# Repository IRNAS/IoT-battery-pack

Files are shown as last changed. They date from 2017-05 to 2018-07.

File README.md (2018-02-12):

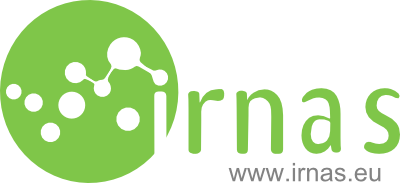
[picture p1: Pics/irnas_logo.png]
irnas_logo


# PiRA - Power in Responsive Applications (IoT battery pack - modular)

This repository contains the design of [PiRA](http://irnas.eu/pira), a modular IoT battery pack based on the integrated version developed for [Safecst Solarcast](https://github.com/IRNAS/Solarcast) sensor device. It is an open source universal solution for solar powered IoT devices implementing all commonly required features:

1. charging,
2. battery monitoring,
3. voltage regulation,
4. power scheduling,
5. battery protection,
6. standard LiPo cell usage,
7. optional on board processor.

This battery pack solution was designed to reduce the development time and costs of bringing IoT devices from idea to functional prototypes.

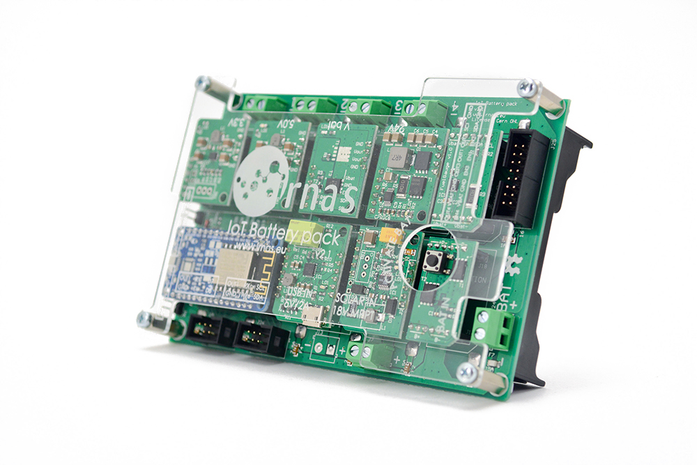
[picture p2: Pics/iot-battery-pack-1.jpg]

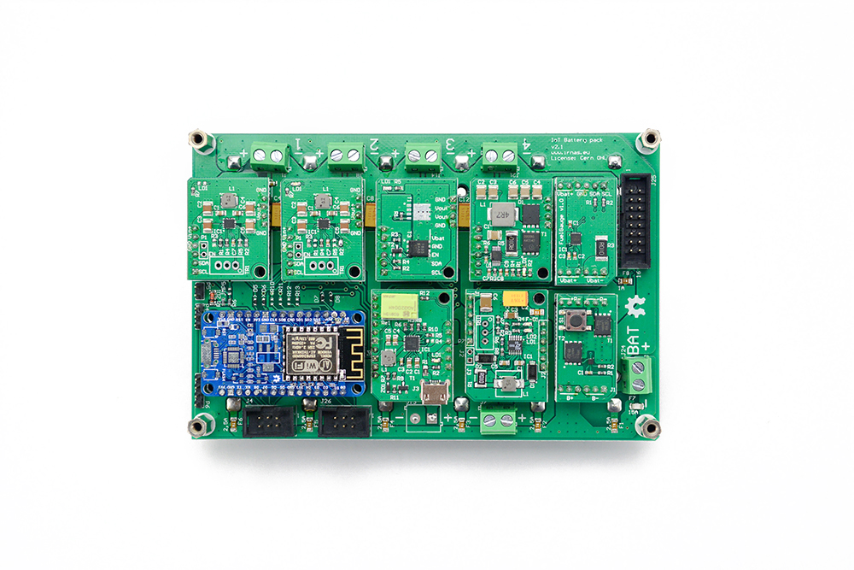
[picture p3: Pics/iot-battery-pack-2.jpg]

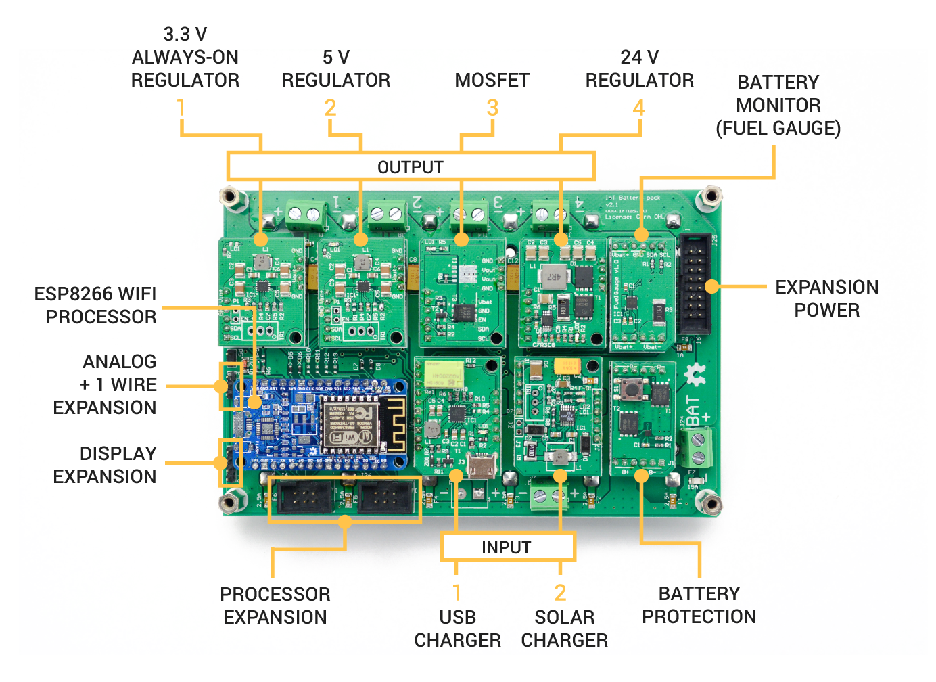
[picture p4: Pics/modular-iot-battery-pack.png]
IoT modular


## GENERAL DESCRIPTION

IoT battery pack is an universal solution for solar powered IoT projects implementing all commonly required features, such as charging, battery monitoring and voltage regulations, to solve these repeating requirements for a number of projects, creating a cost and convenience benefit for developers and manufacturers of IoT systems. Due to the modular structure one can either use this as a set of modules to be included in the target application or simply pack a mother board with a number of modules required for a particular system.

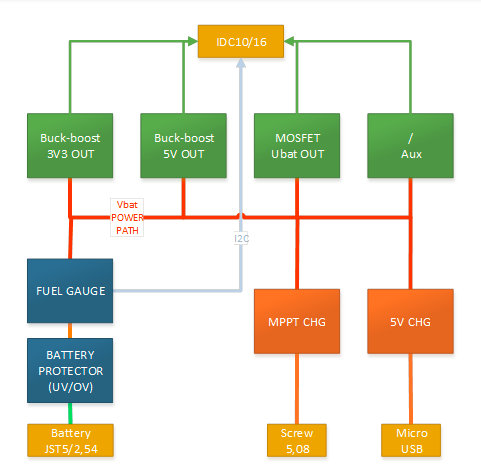
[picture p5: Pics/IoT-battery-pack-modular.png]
IoT modular


The system is broken down into standalone modules one can combine in a number of ways.

## Charging modules
Charging modules provide the interface between a power source and the single cell battery.

 * USB charger: Designed to charge via a standard microUSB: 5V/2A
   * auto-disconnect when not plugged in
 * Solar charger: Designed to charge from a solar cell with MPPT : 4.95-32V IN / 2A charging [LT3652](http://www.linear.com/product/LT3652)
   * protection diode for panel
   * adjustable MPPT point

## Output modules
Providing useful output for various applications.

 * Fixed regulator: 3.3V/2A or 5V/1.5A
   * External enable OR Under-voltage OR allways-on
 * Adjustable regulator: 3-5V/1.5A
   * External enable OR Under-voltage OR allways-on
 * High-side switched battery output: 2A+
 * Higher voltage regulator: 24V/300mA
   * adjustable voltage

## Battery modules
Interfacing the battery to the rest of the circuitry.

 * Battery protection module:
   * Over-voltage
   * Under-voltage
 * Battery charge controller - fuel gauge via I2C

## Backplane modules
General purpose or application specific, simple power routing board that can be easily developed and soldered.

 * General purpose backplane
   * Up to 2 charging modules
   * Up to 4 output modules
   * One battery protection module
   * One battery monitoring module
   * 6-8x 18650 socket
   * Nodemcu V2 socket
   * SSD1306 display connector

## Connection pinout

In the picture bellow is the diagram of the connector J25 which is a standard header with 2.54 mm pitch and it provides output power and communication pins:

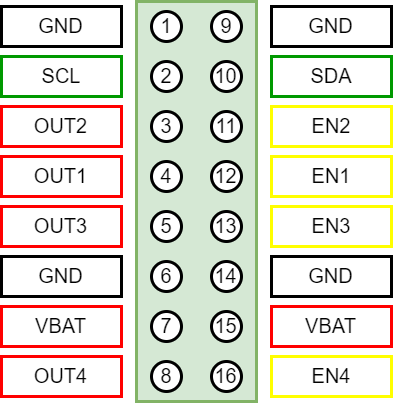
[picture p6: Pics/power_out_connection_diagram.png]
connection_diagram


For more information about the board connections please check the [full connection diagram](/Pics/IoT_BP_connectors_pinout.pdf).

## Instructions on using PiRA battery pack

1. Install 18650 cells (note all must have the same voltage upon installation) or connect an
external battery pack. Optionally connect the I2C display. 
2. Press the "Activate battery" button to activate battery pack.
3. Upon activation the battery pack with the processor is active.
4. After about 60s the SSID: pira-battery-pack_1 Password: configesp will be available for you to
connect.
5. Connect and visit http://192.168.4.1 with your browser.
6. In "Config" tab enter your WiFi SSID and Password. Save changes and go to Tools -> Connect. If
settings are correct the battery pack will be connected to the WiFi network.
7. If the WiFi network is unavailable, the above SSID will appear again.

---

#### License

All our projects are as usefully open-source as possible.

Hardware including documentation is licensed under [CERN OHL v.1.2. license](http://www.ohwr.org/licenses/cern-ohl/v1.2)

Firmware and software originating from the project is licensed under [GNU GENERAL PUBLIC LICENSE v3](http://www.gnu.org/licenses/gpl-3.0.en.html).

Open data generated by our projects is licensed under [CC0](https://creativecommons.org/publicdomain/zero/1.0/legalcode).

All our websites and additional documentation are licensed under [Creative Commons Attribution-ShareAlike 4 .0 Unported License](https://creativecommons.org/licenses/by-sa/4.0/legalcode).

What this means is that you can use hardware, firmware, software and documentation without paying a royalty and knowing that you'll be able to use your version forever. You are also free to make changes but if you share these changes then you have to do so on the same conditions that you enjoy.

Koruza, GoodEnoughCNC and IRNAS are all names and marks of Institut IRNAS Rače. 
You may use these names and terms only to attribute the appropriate entity as required by the Open Licences referred to above. You may not use them in any other way and in particular you may not use them to imply endorsement or authorization of any hardware that you design, make or sell.

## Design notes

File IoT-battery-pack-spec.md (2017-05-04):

# IoT battery pack requirements
IoT battery pack is designed to provide power in various sensing applications, being able to deliver sufficient power for a wide range of sensors for short periods of time and have a long standby operation time between them. BLE interface allows users to configure it as well as provide a communication channel to talk to other sensors in the vicinity.

 * Capacity: 1P-6P Li-Po 18650 (3600mAh - 20000mAh)
  * Batteries connected in 3 branches of two, each branch fuse protected
  * User can connect 1-6 cells in parallel. For safety, no more then two can be directly connected in parallel, thus the 6 cells in parallel are split in 3 pairs of 2 cells in parallel, the sets connected together each via its own fuse.
  * Connector for cells: 2.54 JST (not mounted)
 * Input: 2A at 5V, input range 3-6V
  * DC jack input for solar cell, no diode used
  * Micro USB input for wall-socket (Additionally 2 pads for connections)
  * USB input must disconnect the solar cell and prevent discharge into it, can be done with a relay. Relay powered from USB socket via diode in a way, that NC is solar cell and NO is external 5 V input.
  * Current shall be adjustable from MCU (PWM?) and via trimmer in a way, that voltage is defined, where current is lowered (i.e. at 4V5 system goes to CV mode on input). Dynamic adjustment of charge current, such that the input voltage does not drop below 4.5V or other configurable level if possible. This prevents overloading of the supply, for example when solar cell is connected holds it reasonably close to maximum power output voltage. If possible the voltage level should be software controlled via BLE.

 * Output: 2A at 5V, 1A at 3.3V, direct battery voltage output
  * 5V - High-side switch or DC-DC module disable + fuse
  * 3.3V - High-side switch or DC-DC module disable + fuse
  * battery voltage - High-side switch and a fuse
  * Out connectors 2.54mm header/JST terminal
 * BLE processor (preferred Nordic nRF51822) on board implementing the following features in software:
  * battery voltage and current measurement. All voltages (inputs, outputs), current is measured through Fuel gauge chip via I2C
  * configurable thermal protection/shutdown via fuel gauge I2C
  * configurable battery charge voltage (over-voltage protection) via fuel gauge I2C
  * configurable battery discharge voltage (under-voltage protection) via fuel gauge I2C
  * I2C interface (nRF51822 SDA 10, SCL 8)
  * Enable/disable outputs as defined above
  * Expose remaining GPIO, about 8-10 are sufficient (to 10 pin header vcc/+3v3+8gpios)
  * RG(B) LED from MCU, software controlled and can be disabled fully
  * Standard Cortex programming connector
  * [Grove I2C connector](http://wiki.seeed.cc/Grove-I2C_Hub/)
 * Simultaneous charging and discharging
 * Low quiescent current - standby mode with 3.3V branch active no more then 100uA battery discharge current
 * Input DC-DC with current limiter
  * Dynamic adjustment of charge current, such that the input voltage does not drop below 4.5V or other configurable level if possible. This prevents overloading of the supply, for example when solar cell is connected holds it reasonably close to maximum power output voltage. If possible the voltage level should be software controlled via BLE.

 * Target production cost ~15EUR@1k
  * Batteries excluded
 * Prototyping process: 10 units for testing in first batch, 30 units in second batch

## Diagram
Diagram is made in http://draw.io

diagram

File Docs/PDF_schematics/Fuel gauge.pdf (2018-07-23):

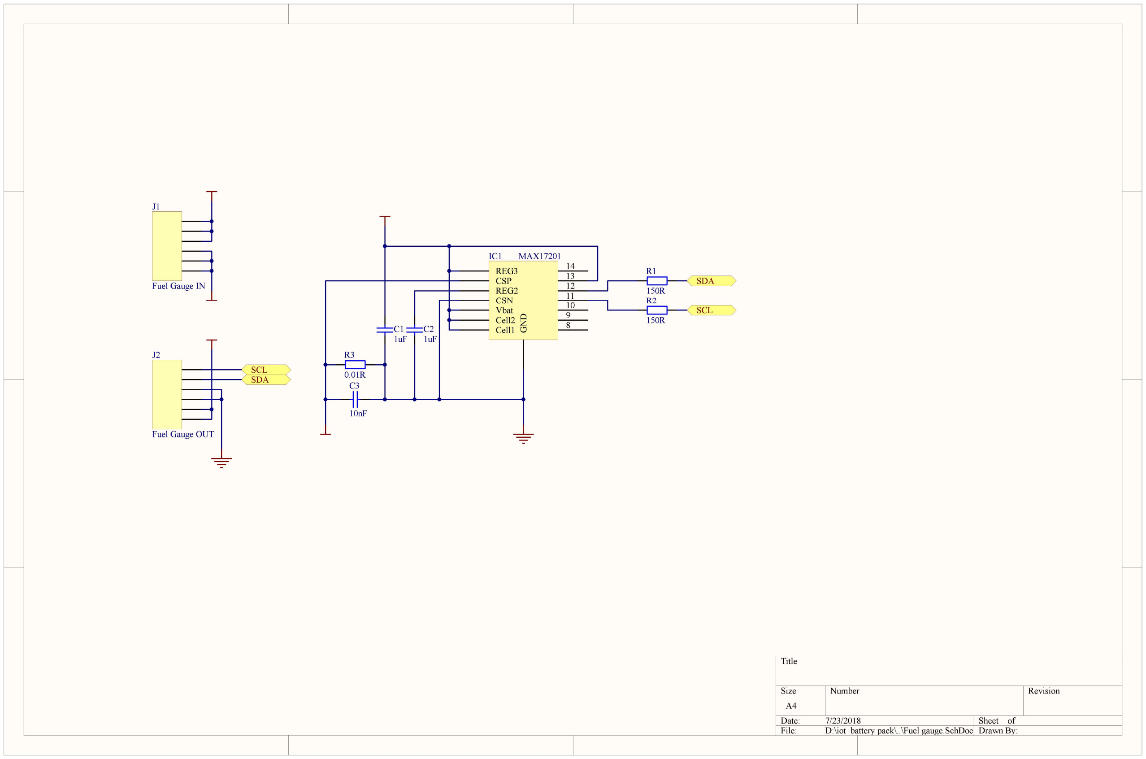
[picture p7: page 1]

Title

Size | Number | Revision
A4
Date: | 7/23/2018 | Sheet of
File: | D:\iot_battery pack\..\Fuel gauge.SchDoc Drawn By:

J1

Fuel Gauge IN

J2

Fuel Gauge OUT

SCL
SDA

REG3
CSP
REG2
CSN
Vbat
Cell2
Cell1 | 8
| 9

10

11

12

13

### 14 GND

IC1 MAX17201

SCL

SDA

150R

R2

150R

R1

1uF

C2
1uF

C1

0.01R

R3

10nF

C3

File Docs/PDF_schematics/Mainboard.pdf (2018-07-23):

## OUTPUT MODULES

## CHARGER MODULES EN⁴ EN³ EN¹ EN²

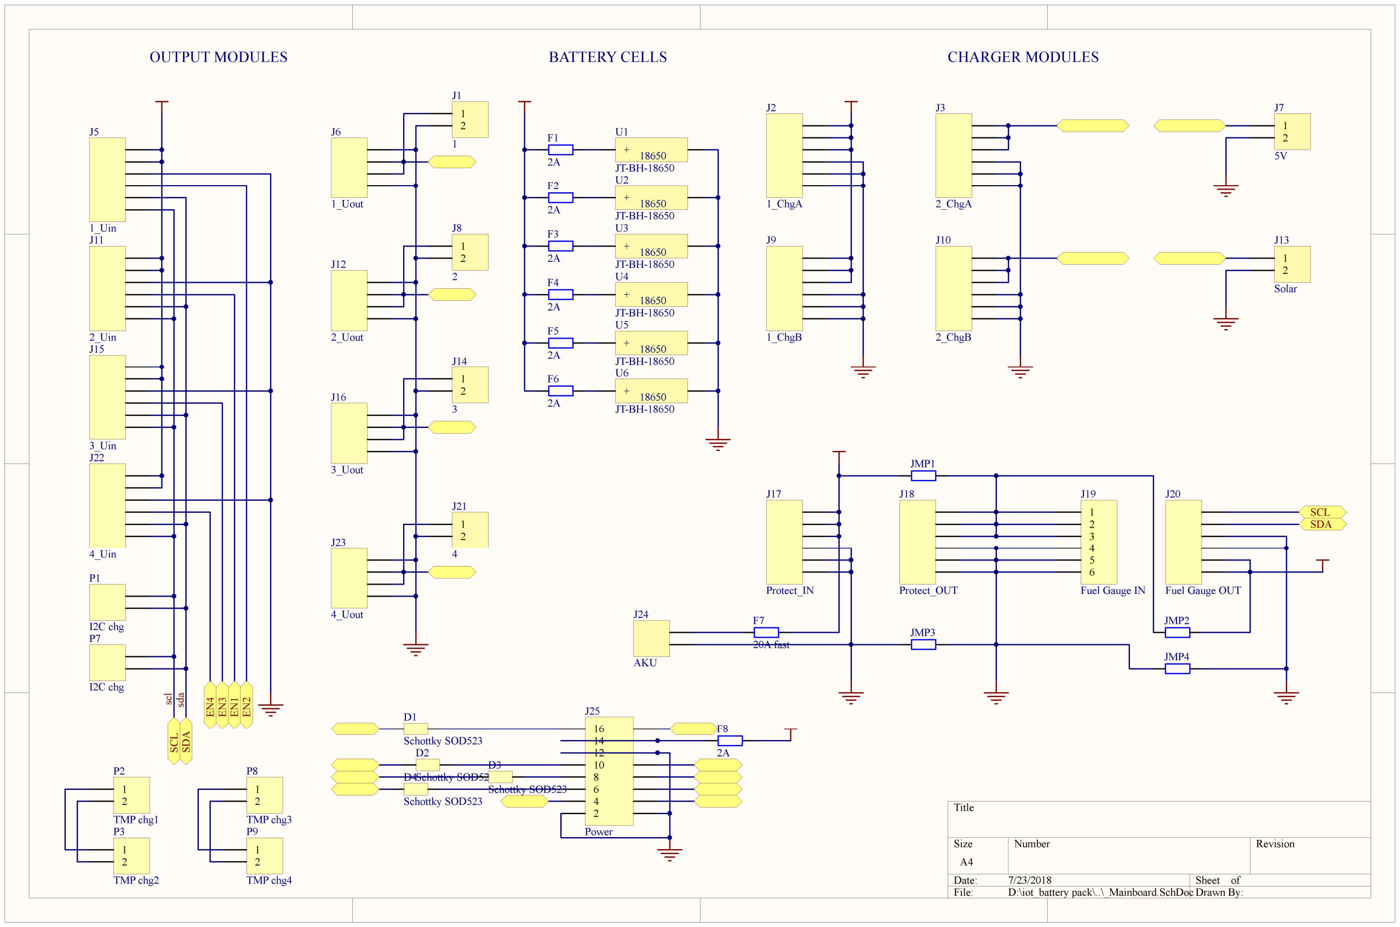
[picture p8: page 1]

Title

Size | Number | Revision
A4
Date: | 7/23/2018 | Sheet of
File: | D:\iot_battery pack\..\_Mainboard.SchDoc Drawn By:

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
Power

1
2

J13

Solar

1
2

J7

5V

J5

1_Uin
J11

2_Uin
J15

3_Uin
J22
4_Uin | SCL SDA

J6

1_Uout

J12

2_Uout

J16

3_Uout

J23

4_Uout

J2

1_ChgA

J9

1_ChgB

J3

2_ChgA

J10

2_ChgB

J17

Protect_IN

J18

Protect_OUT

1
2
3
4
5
6

J19

Fuel Gauge IN

J20

Fuel Gauge OUT

J24

AKU

JMP3

SCL
SDA

JMP4

JMP2

JMP1

+
18650

U1

JT-BH-18650

+
18650

U2

JT-BH-18650

+
18650

U3

JT-BH-18650

+
18650

U4

JT-BH-18650

+
18650

U5

JT-BH-18650

+
18650

U6

JT-BH-18650

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
## BATTERY CELLS

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
Schottky SOD523
D2

Schottky SOD523

D3

Schottky SOD523

D4

Schottky SOD523 scl sda

2A

F8

20A fast

F7

P1

I2C chg

1
2

P2

TMP chg1

1
2

P3

TMP chg2

1
2

P8

TMP chg3

1
2

P9

TMP chg4

P7

I2C chg

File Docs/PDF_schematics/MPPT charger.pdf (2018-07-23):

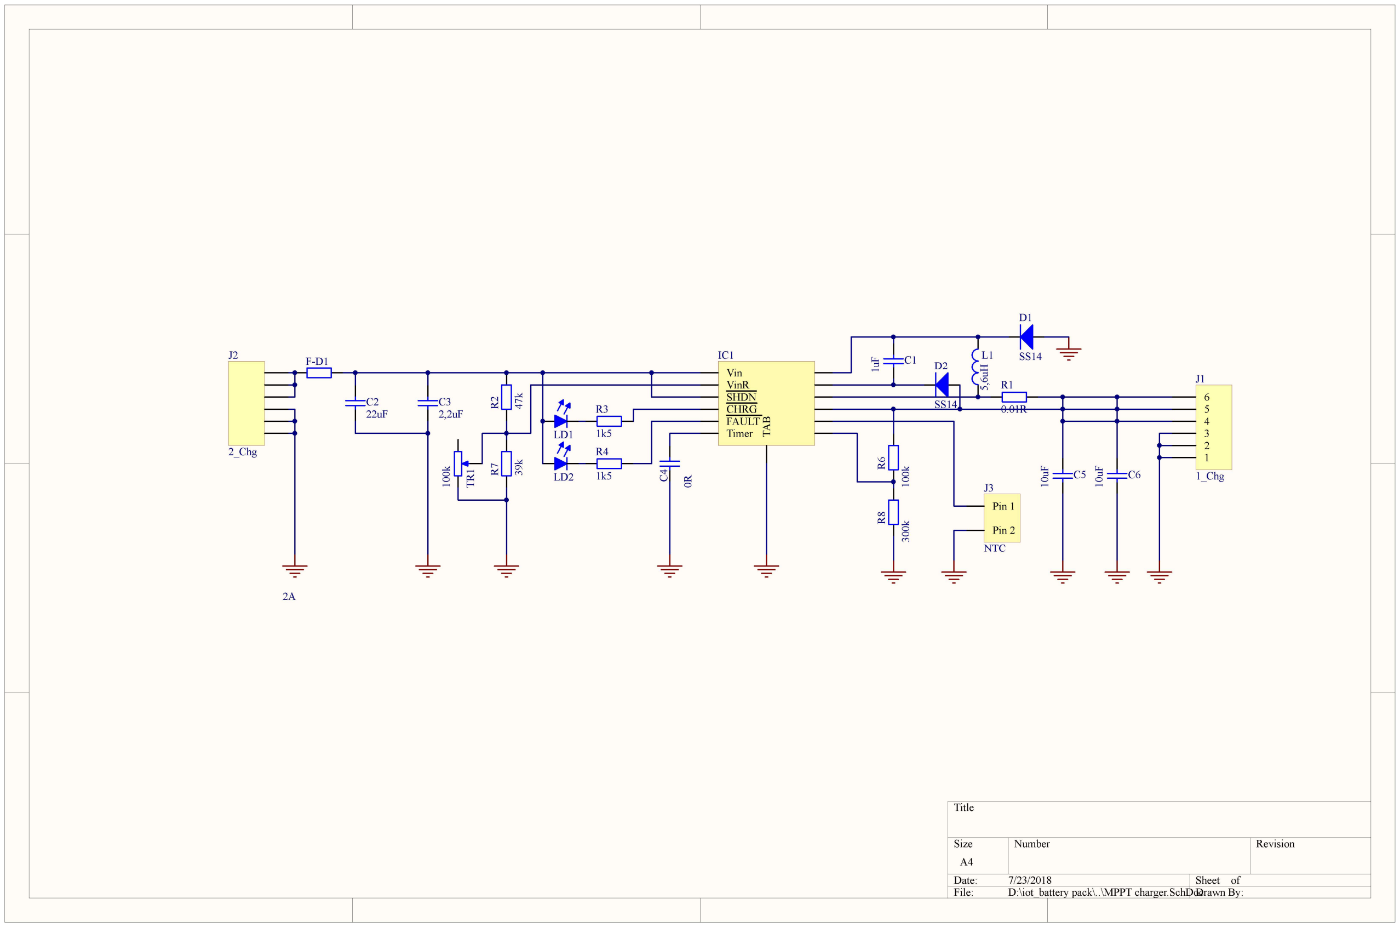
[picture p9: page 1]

Title

Size | Number | Revision
A4
Date: | 7/23/2018 | Sheet of
File: | D:\iot_battery pack\..\MPPT charger.SchDocDrawn By:

1

2

3

4

5

6

J1

1_Chg

J2
2_Chg | 5,6uH
L1 0RC⁴ | 1uF | C1

LD1

LD2

Vin
VinR
SHDN
CHRG
FAULT
Timer TAB

IC1

1k5

R3 100k TR¹

Pin 1

Pin 2

J3

NTC

2A

F-D1

22uF

C2
2,2uF

C3

1k5

R4 R² | 47k R⁷ | 39k | 100kR⁶ | 300kR⁸

D2

SS14 | 10uF | C5
0.01R

R1

D1

SS14 | 10uF | C6

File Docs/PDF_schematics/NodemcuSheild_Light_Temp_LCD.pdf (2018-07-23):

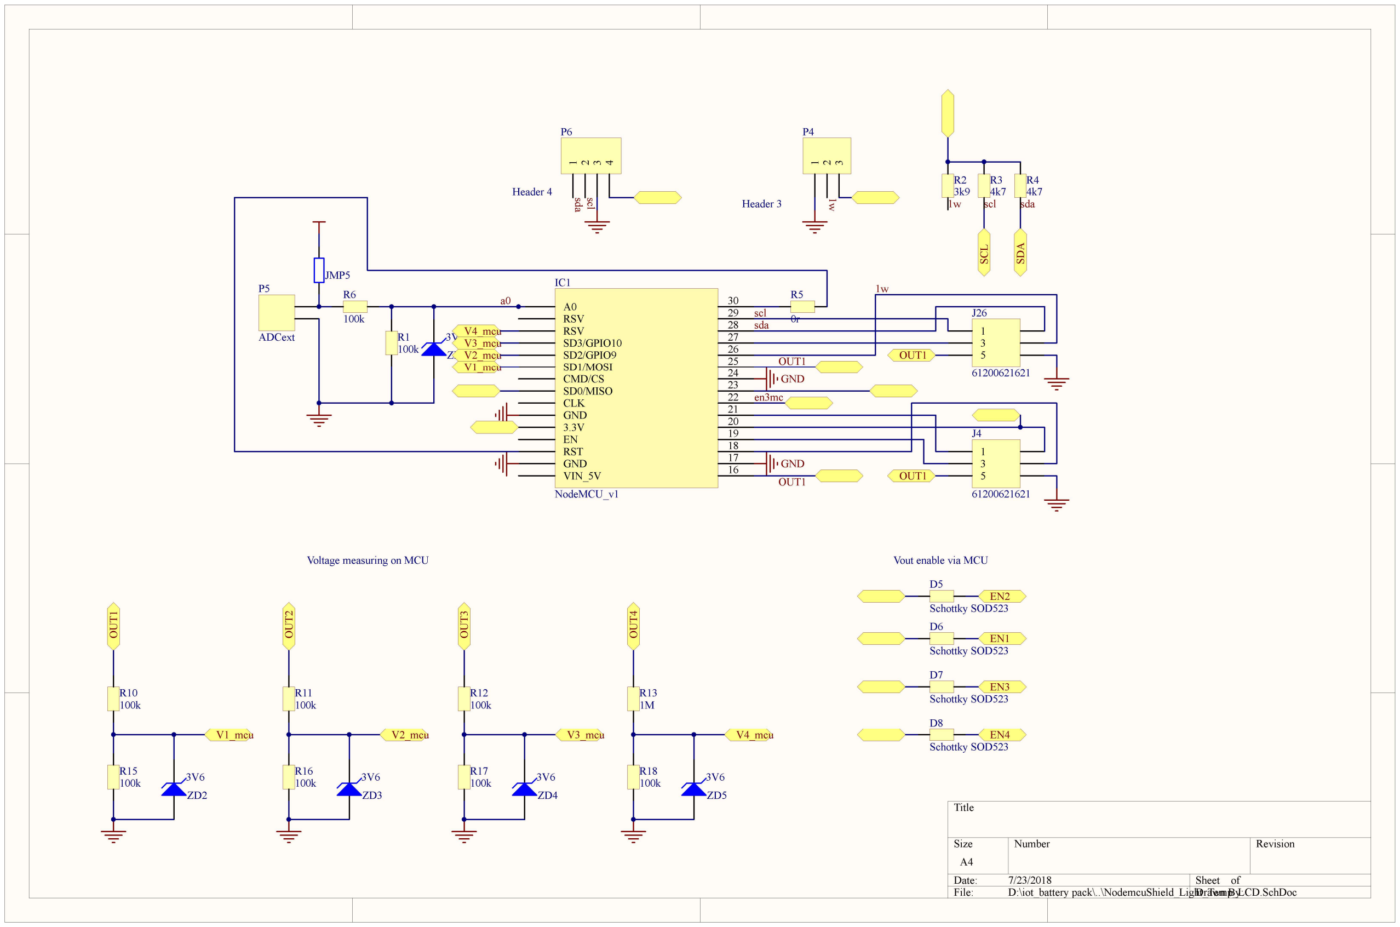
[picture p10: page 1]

Title

Size | Number | Revision
A4
Date: | 7/23/2018 | Sheet of
File: | D:\iot_battery pack\..\NodemcuShield_Light_Temp_LCD.SchDoc Drawn By:

A0
RSV
RSV
SD3/GPIO10
SD2/GPIO9
SD1/MOSI
CMD/CS
SD0/MISO
CLK
GND
3.3V
EN
RST
GND
VIN_5V | 16
| 17

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
NodeMCU_v1

1

2

3

P4

Header 3

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
scl ¹w | 1w

R2
3k9

P5

ADCext

R6

100k

a0 | 1

2

3

4

P6

Header 4 sda scl

R1
100k

3V6
ZD1

JMP5
R5

0r
1
3
5

J26

61200621621

1
3
5

J4

61200621621

OUT1 | OUT1

OUT1

EN4

EN3

EN2

EN1

D5

Schottky SOD523
D6

Schottky SOD523

D7

Schottky SOD523

D8

Schottky SOD523 OUT¹

Voltage measuring on MCU | Vout enable via MCU

R15
100k

R10
100k

3V6
ZD2

V1_mcu OUT² R16

100k

R11
100k

3V6
ZD3

V2_mcu OUT³ R17

100k

R12
100k

3V6
ZD4

V3_mcu OUT⁴ R18

100k

R13
1M

3V6
ZD5

V4_mcu

V1_mcu

V2_mcu

V3_mcu

V4_mcu

OUT1 | SCL | SDA

1w

en3mc

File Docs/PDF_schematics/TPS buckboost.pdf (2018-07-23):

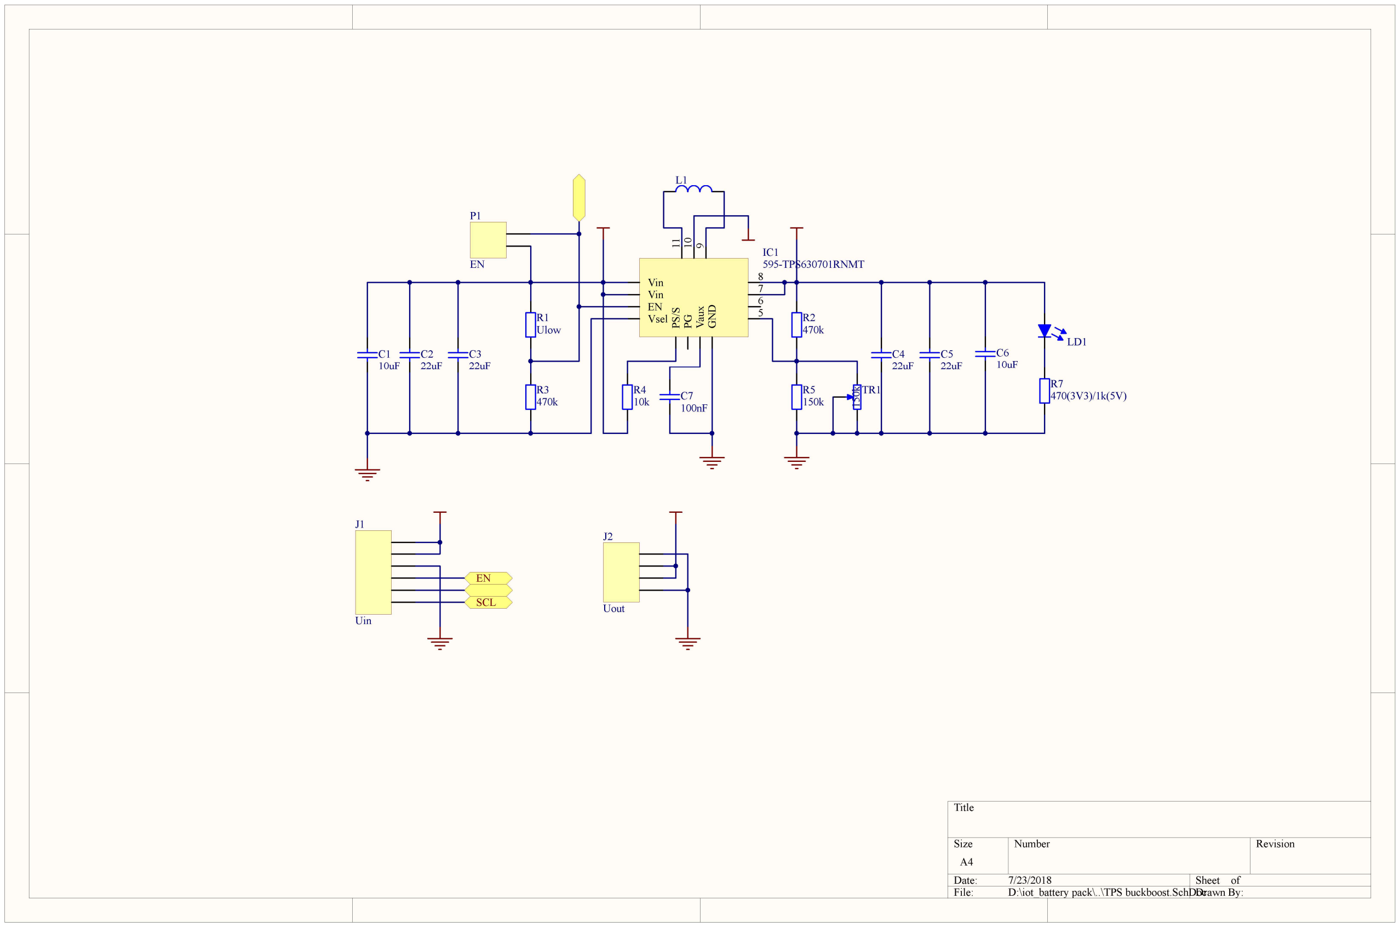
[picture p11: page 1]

Title

Size | Number | Revision
A4
Date: | 7/23/2018 | Sheet of
File: | D:\iot_battery pack\..\TPS buckboost.SchDocDrawn By:

Vin
EN
Vsel PS/S PGVaux GND | 5
| 6

### 7 ¹¹¹⁰

9

### 8 Vin

595-TPS630701RNMT

IC1

J1

Uin

J2

Uout

L1

150k

R5

470k

R2

22uF

C4
22uF

C5
22uF

C2
22uF

C3

10k

R4

Ulow

R1

470k

R3

10uF

C6
10uF
C1 | 150kTR1

SCL

EN

470(3V3)/1k(5V)

R7

100nF

C7

LD1

P1

EN

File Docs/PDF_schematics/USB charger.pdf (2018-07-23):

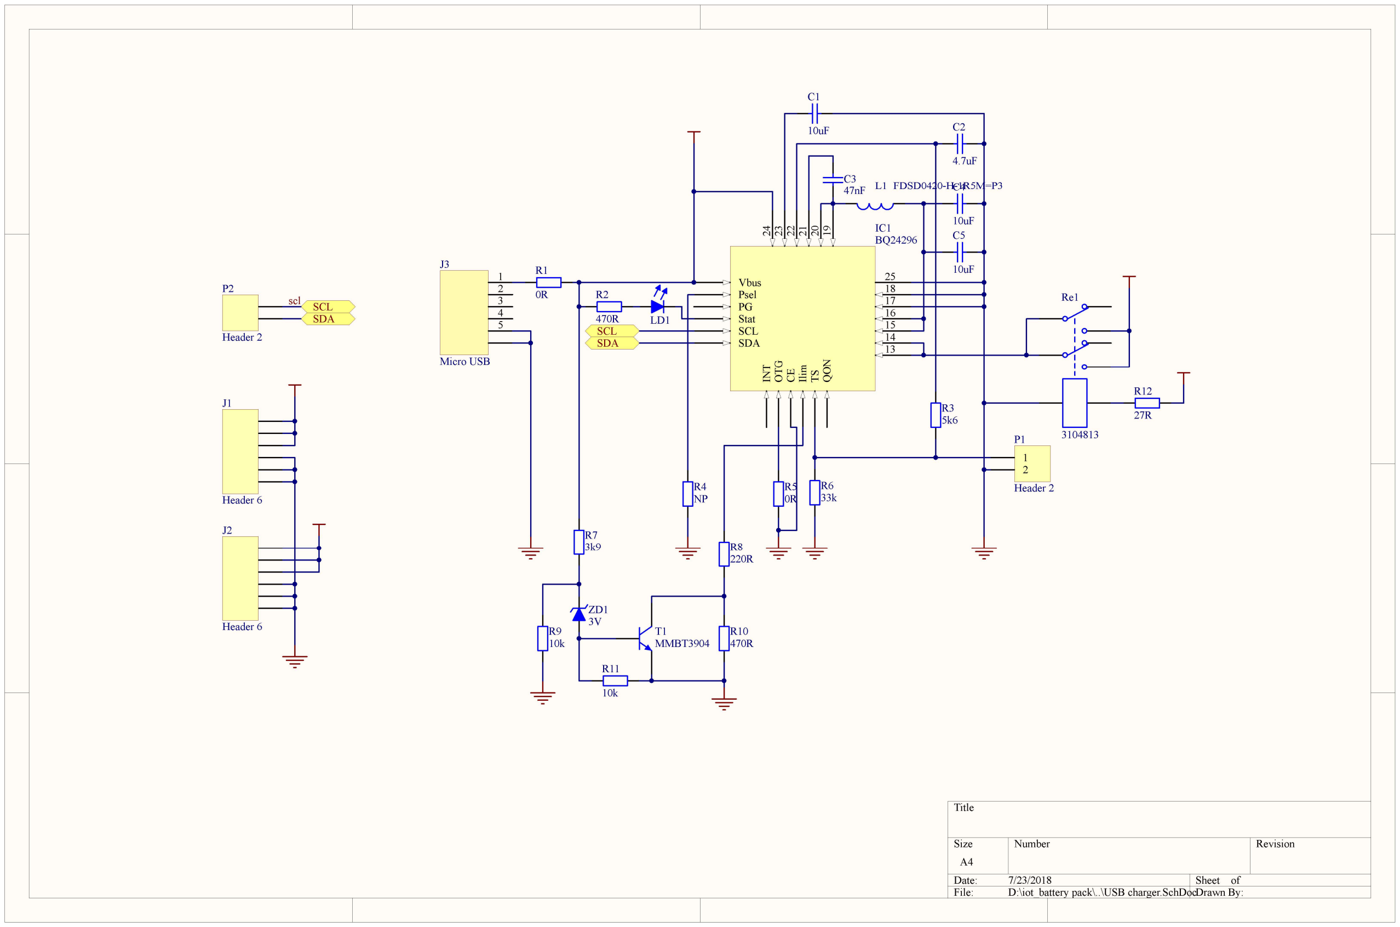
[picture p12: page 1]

Title

Size | Number | Revision
A4
Date: | 7/23/2018 | Sheet of
File: | D:\iot_battery pack\..\USB charger.SchDocDrawn By:

J1

Header 6

J2

Header 6

1
2
3
4
5

J3

Micro USB

10uF

L1 FDSD0420-H-1R5M=P3 C4 47nF

C3

Vbus
Psel
PG
Stat
SCL
SDA INT OTG CEIlimTSQON
13

14

15

16

17

### 18 ²⁴²³²²²¹²⁰¹⁹

25

IC1
BQ24296

33k

R6

5k6

R3

4.7uF

C2

1
2

P1

Header 2

0R

R1

10uF

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
470R LD1

R2

220R

R8

470R

T1 | R10
MMBT3904

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
3104813

Re1

27R

R12

10uF

C5

P2

Header 2

scl

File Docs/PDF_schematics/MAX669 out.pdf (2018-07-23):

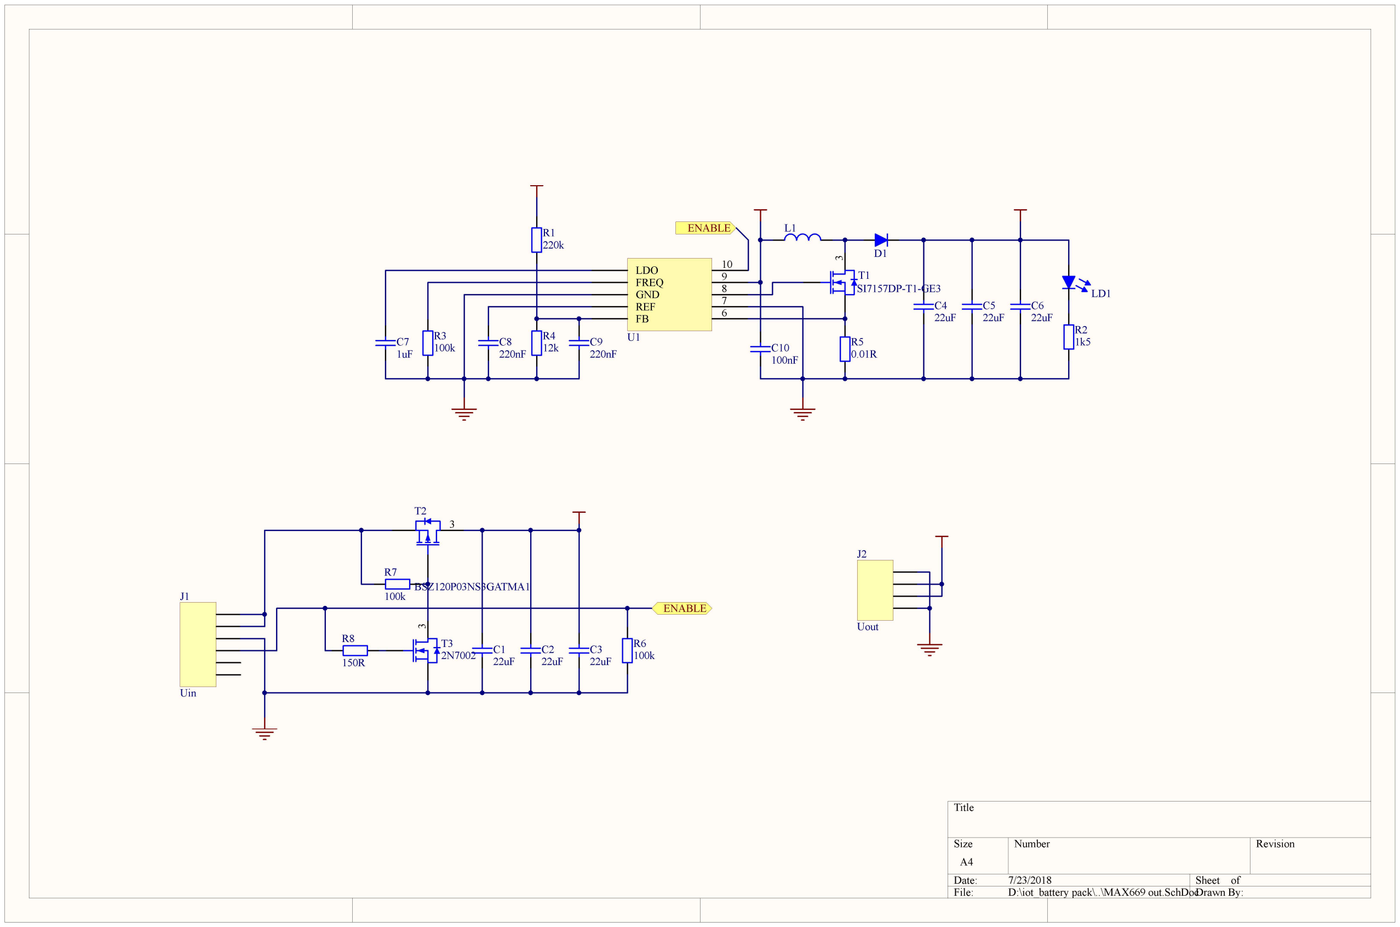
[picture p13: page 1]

Title

Size | Number | Revision
A4
Date: | 7/23/2018 | Sheet of
File: | D:\iot_battery pack\..\MAX669 out.SchDocDrawn By:

J1

Uin

J2

Uout

LDO
FREQ
GND
REF
FB | 6
| 7

8

9

10

U1

ENABLE

ENABLE

220nF

C8 100k

R3

22uF

C1
22uF

C2
22uF

C3

22uF

C4
22uF

C5
22uF

C6

L1

0.01R

R5 ³

SI7157DP-T1-GE3

T1

D1

12k

R4
220nF

C9

220k

R1

1uF

C7

LD1

1k5

R2

100k

R6

100nF

C10

3

BSZ120P03NS3GATMA1

T23

2N7002

T3

100k

R7

150R

R8

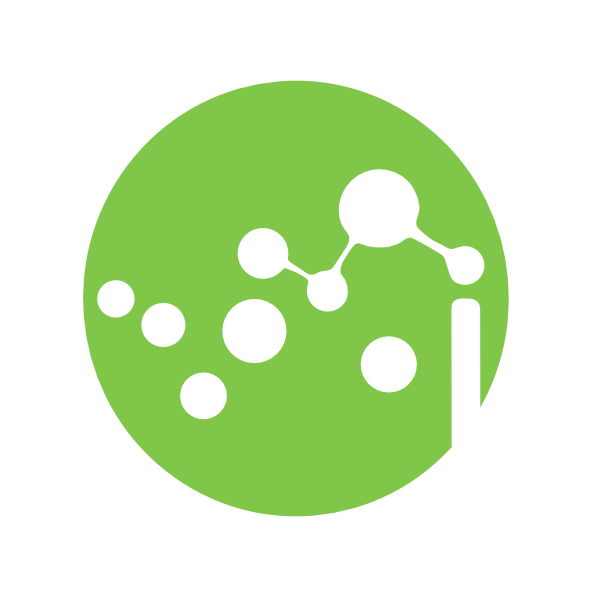
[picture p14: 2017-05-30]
Docs/Templates/images/irnas-krog.png

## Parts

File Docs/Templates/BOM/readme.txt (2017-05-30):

When generating BOM in Altium designer check fields:
* Manufacturer Part Number 1
* Manufacturer 1
* Description
* Footprint
* Category
* Quantity
* Supplier 1 (all)

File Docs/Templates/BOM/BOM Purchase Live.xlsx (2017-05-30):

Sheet: Part List Report
 | Component list |  |  | Field=ProjectTitle
 | Source Data From: | Field=DataSourceFileName |  |  | Contact:
 | Project: | Field=ProjectFileName
 | Variant: | Field=VariantName |  |  |  |  |  |  | IRNAS
 | Report Date: | Field=ReportDate | Field=ReportTime |  |  |  |  |  | www.irnas.eu
 | Print Date: | 2017-05-15 | 17:12:05
# | Column=Manufacturer Part Number 1 | Column=Manufacturer 1 | Column=Description | Column=Footprint | Column=Category | Column=Quantity | Column=Supplier 1 | Column=Supplier Part Number 1 | Column=Supplier Order Qty 1 | Column=Supplier Stock 1 | Column=Supplier Unit Price 1 | Column=Supplier Subtotal 1 | Column=Supplier Currency 1
1
2
3
 |  |  |  |  |  | 0 |  |  | 0 |  |  | 0
Approved |  |  |  | Notes
 |  |  |  |  |  | Field=ProductionQuantity | pcs: | Total |  | 0 |  | Field=Currency
 |  |  |  |  |  |  |  | Price for 1pcs |  | #VALUE! |  | Field=Currency

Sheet: Project Information
Project Full Path | Field=ProjectFullPath
Project Filename | Field=ProjectFileName
Variant Name | Field=VariantName
Data-Source Filename | Field=DataSourceFileName
Data-Source Full Path | Field=DataSourceFullPath
Title | Field=Title
Total Quantity | Field=TotalQuantity
Report Time | Field=ReportTime
Report Date | Field=ReportDate
Report Date & Tine | Field=ReportDateTime
Output Name | Field=OutputName
Output Type | Field=OutputType
Output Generator Name | Field=GeneratorName
Output Generator Description | Field=GeneratorDescription

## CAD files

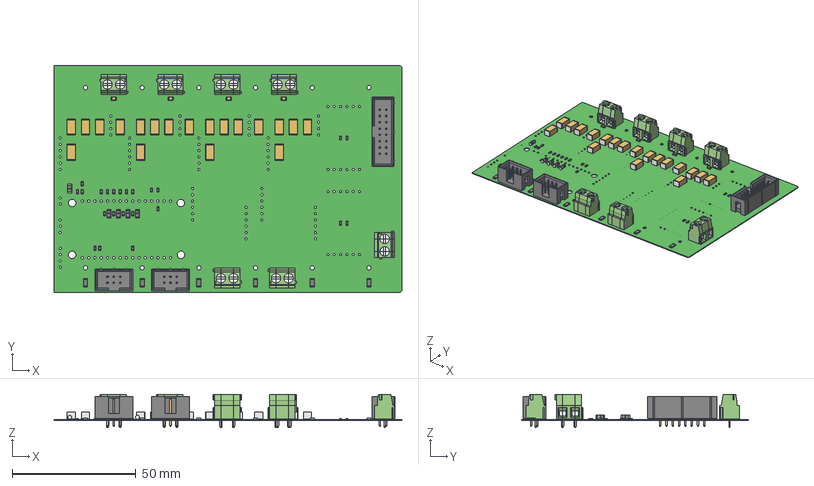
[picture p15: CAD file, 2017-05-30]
Docs/3D_models/_Mainboard.step
140.3 x 91.4 x 13.5 mm
Board
leftPin x 5
rightPin x 5
Mid_Body x 29
Open_CASCADE_STEP_translator_6.8_4.2.1 x 46
Mark x 29
CII5_08_SX_PRT.PRT x 7
CII5_08_CNT_PRT.PRT x 7
CII5_08_DX_PRT.PRT x 7
6120xx21621_PIN x 28
Open_CASCADE_STEP_translator_6.8_7.2.1 x 12
Open_CASCADE_STEP_translator_6.8_32.1.1 x 19
Open_CASCADE_STEP_translator_6.8_32.1.2 x 19
Open_CASCADE_STEP_translator_6.8_32.2.1 x 19
Open_CASCADE_STEP_translator_6.8_17.1.1 x 4
Open_CASCADE_STEP_translator_6.8_17.1.2 x 4
Open_CASCADE_STEP_translator_6.8_17.2.1 x 4

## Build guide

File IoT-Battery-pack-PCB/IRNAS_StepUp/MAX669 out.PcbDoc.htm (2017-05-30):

Reporting Options

# File in Newer Format

Date | : | 29.5.2017
Time | : | 9:19:50
Filename | : | C:\Users\Uporabnik\Downloads\IoT-Battery-pack\MAX669 out.PcbDoc

Version | Warning
Release 17.0 | CAUTION - Component parameters added.
Release 17.0 | CAUTION - Supports of backdrilling
Release 17.1 | CAUTION - Support of waived violations
Release 17.1 | CAUTION - Support of object specific keepouts

This file was generated by a later version of the software

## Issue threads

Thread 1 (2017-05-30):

Mounting holes must be holes, not vias

SloMusti, 2017-05-30:
All mounting holes must be designed as Holes, not Vias as they are otherwise not exported in DXF and STEP models and make integration with hardware difficult.

mucek, 2017-06-06:
Done

Closed 2017-06-06.

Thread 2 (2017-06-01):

Add a RPi header to the main board

SloMusti, 2017-06-01:
Add a RPi header to the main board, such that it can be directly connected to it.

Additional:
- jumper selection for which regulator power RPi
- mosfet or other circuit such that RPi can hold itself turned on
- connection to I2C

SloMusti, 2017-06-06:
Will be implemented separately.

Closed 2017-06-06.

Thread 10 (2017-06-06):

TPS_buckboost: Do not populate LEDs

SloMusti, 2017-06-06:
Do not populate LEDs on this module

mucek, 2017-06-11:
Led is NP on 3V3 variant. 5V variant has led set as populated.

Closed 2017-06-11.

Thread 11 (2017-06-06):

Charging modules: add I2C on charger module connector as such

SloMusti, 2017-06-06:
Add I2C on charger module connector as such, so charging modules can be i2c connected directly to the board.

Closed 2017-06-11.

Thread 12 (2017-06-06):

NodeMCU footprint is wrong, flipped upside-down

SloMusti, 2017-06-06:
See images how it is currently flipped and the correct orientation.

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

Closed 2017-06-11.

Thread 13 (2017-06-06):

Main board: move headers P5 and P4

SloMusti, 2017-06-06:
Move headers P5 and P4 left towards output modules, to avoid clash with USB on NodeMCU.

Closed 2017-06-11.

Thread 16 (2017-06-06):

Add test-points to measure voltages befgore-after modules and such

SloMusti, 2017-06-06:
Add test-points to measure voltages before-after modules and such, so debugging and testing can be simple with multimeter probes from the top side.

mucek, 2017-06-11:
Can be done on module terminals now, when pinout is in top silk.

Closed 2017-06-11.

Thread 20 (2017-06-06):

Main board: P6 I2C pinout silkscreen incorrect

SloMusti, 2017-06-06:
P6 I2C pinout silkscreen is incorrect, SCL and SDA are swapped.

Closed 2017-06-11.

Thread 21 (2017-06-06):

Main board: I2C connection split

SloMusti, 2017-06-06:
I2C connection is split in two branches, should be one, can be joined via a jumper resistor.

mucek, 2017-06-11:
Joined, no jumpers

Closed 2017-06-11.

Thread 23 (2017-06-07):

Power consumption analysis

SloMusti, 2017-06-07:
Tests have been performed to determine the power consumption of modules as such in the battery pack in their default - off state, unless otherwise noted.

* Battery protection: 4uA
* Fuel gauge: 30uA
* MPPT Solar charger: 16uA
* 3v3 regulator - always on: 80uA
* USB charger: 0uA - relay disconnected
* 5V regulator - off: 2uA
* MOSFET output: 1uA

Total power consumption of the motherboard with all modules present, 3v3 output active is 133uA.

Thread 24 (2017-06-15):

Connector J25 pinout

VojislavM, 2017-06-15:
Current pinout of connector J25 is not OK.
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

SW1 and SW2 pins are inverted

This is because of the error in the schematics EN2 is connected to the J5 instead of J11, and EN1 is connected to the J11 instead of J5.

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

VojislavM, 2017-06-15:
This is how it should be:
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

mucek, 2017-06-19:
Replaced connection between J25 and schottky diodes. Net names (EN1, EN2) in schematics are still wrong and should be replaced (EN1 > EN2, EN2 > EN1)

Closed 2017-06-19.

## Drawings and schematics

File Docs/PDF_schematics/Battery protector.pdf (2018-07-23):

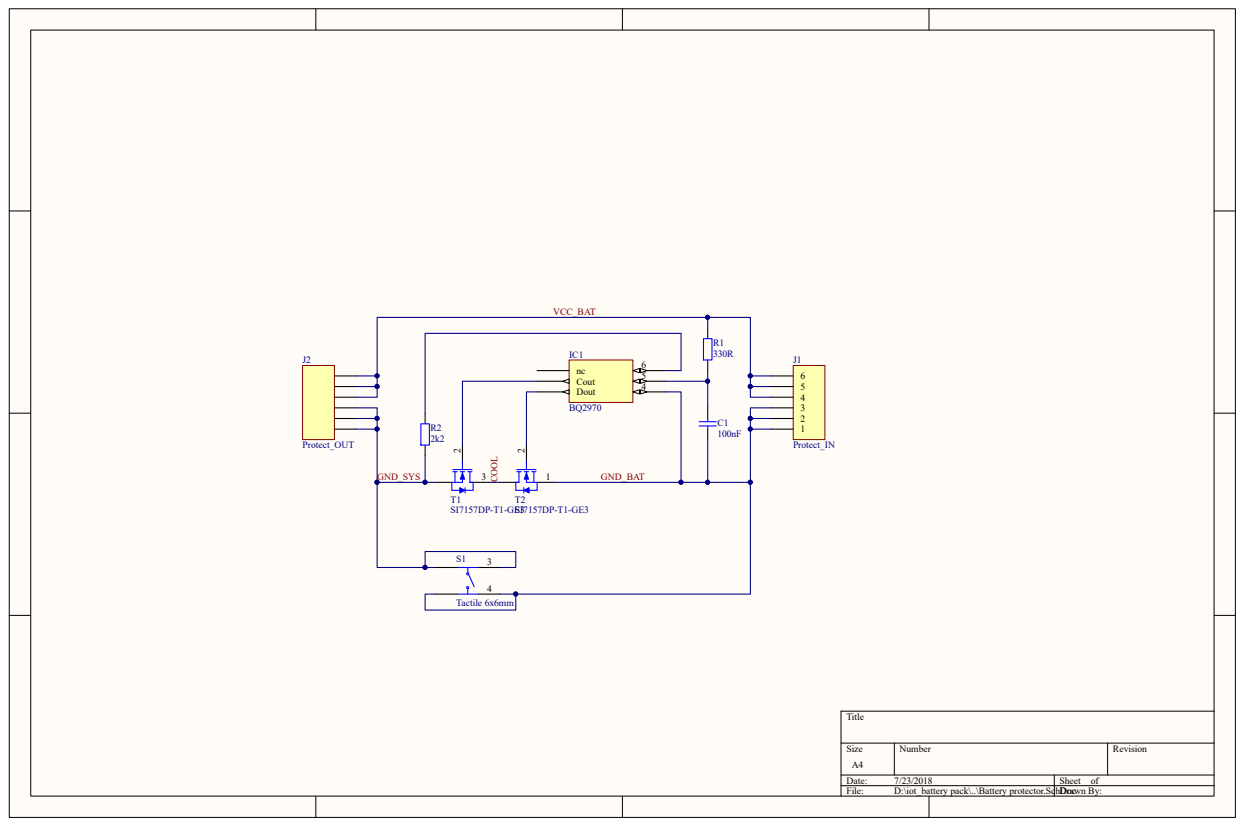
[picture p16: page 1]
Title; Size; Number; Revision; Date:; Sheet of; File:; D:\iot_battery pack\..\Battery protector.SchDocrawn By:; Protect_IN; Protect_OUT; nc Cout; Dout; GND_SYS; GND_BAT; VCC_BAT COOL; Tactile 6x6mm

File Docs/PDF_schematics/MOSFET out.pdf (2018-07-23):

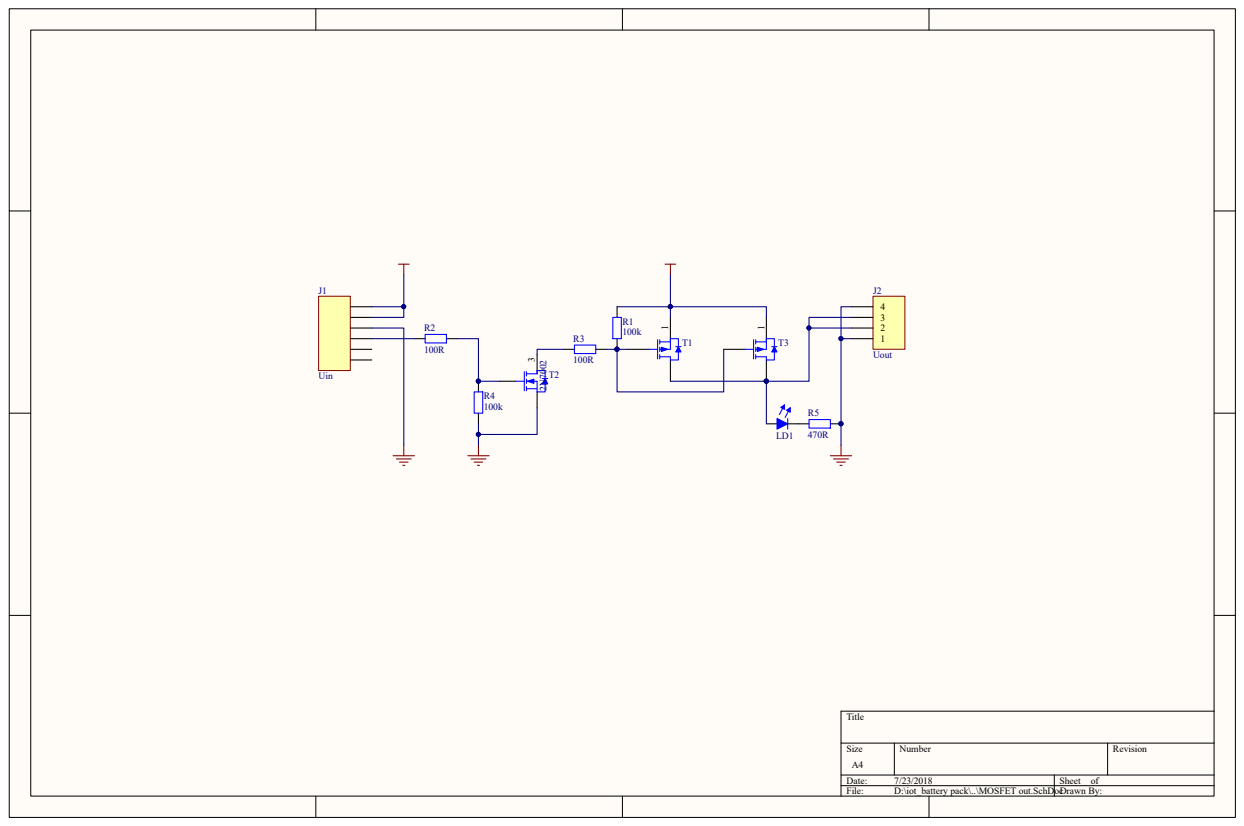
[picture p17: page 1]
Title; Size; Number; Revision; Date:; Sheet of; File:; D:\iot_battery pack\..\MOSFET out.SchDocDrawn By:; Uin; Uout 3 2N⁷⁰⁰² T2

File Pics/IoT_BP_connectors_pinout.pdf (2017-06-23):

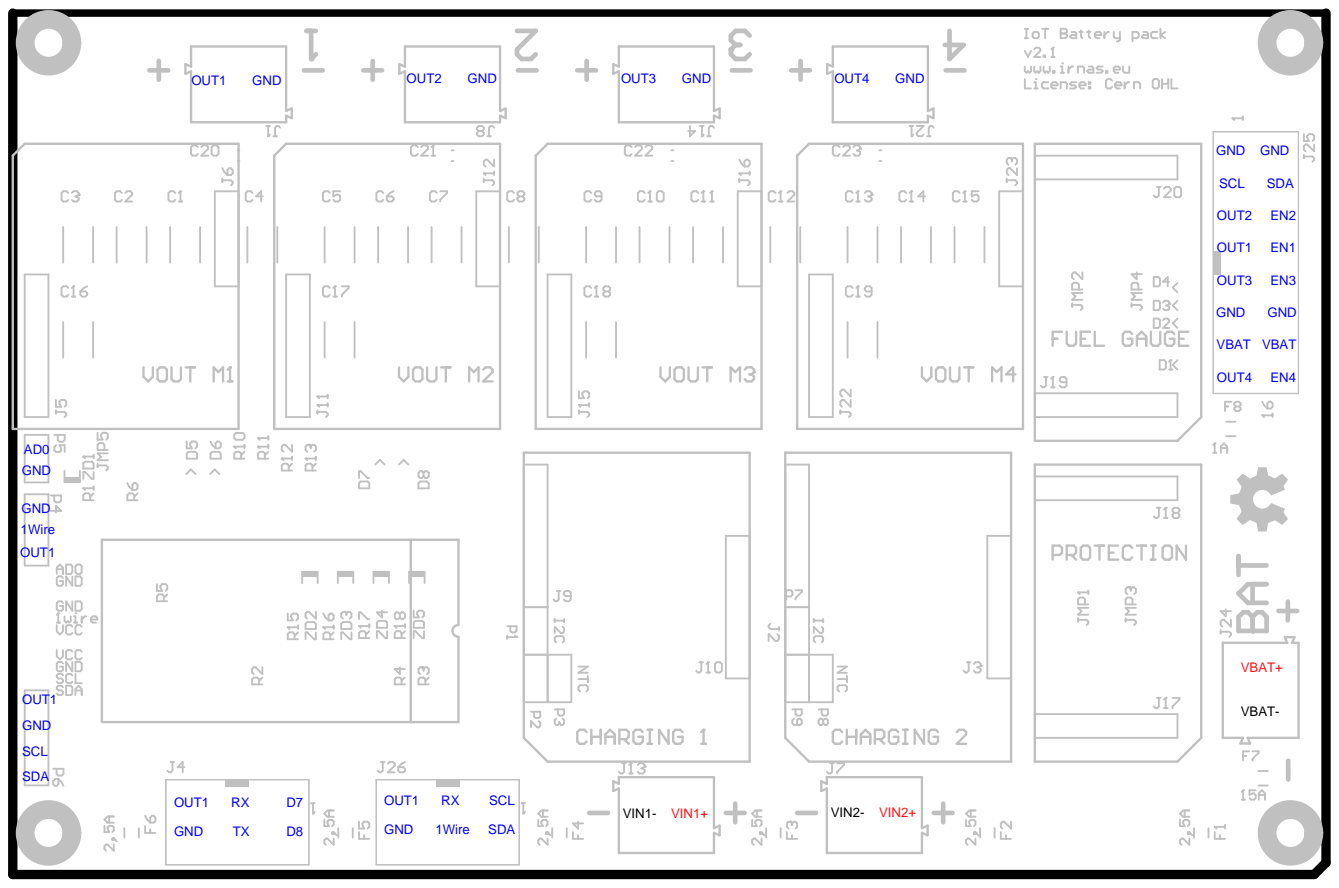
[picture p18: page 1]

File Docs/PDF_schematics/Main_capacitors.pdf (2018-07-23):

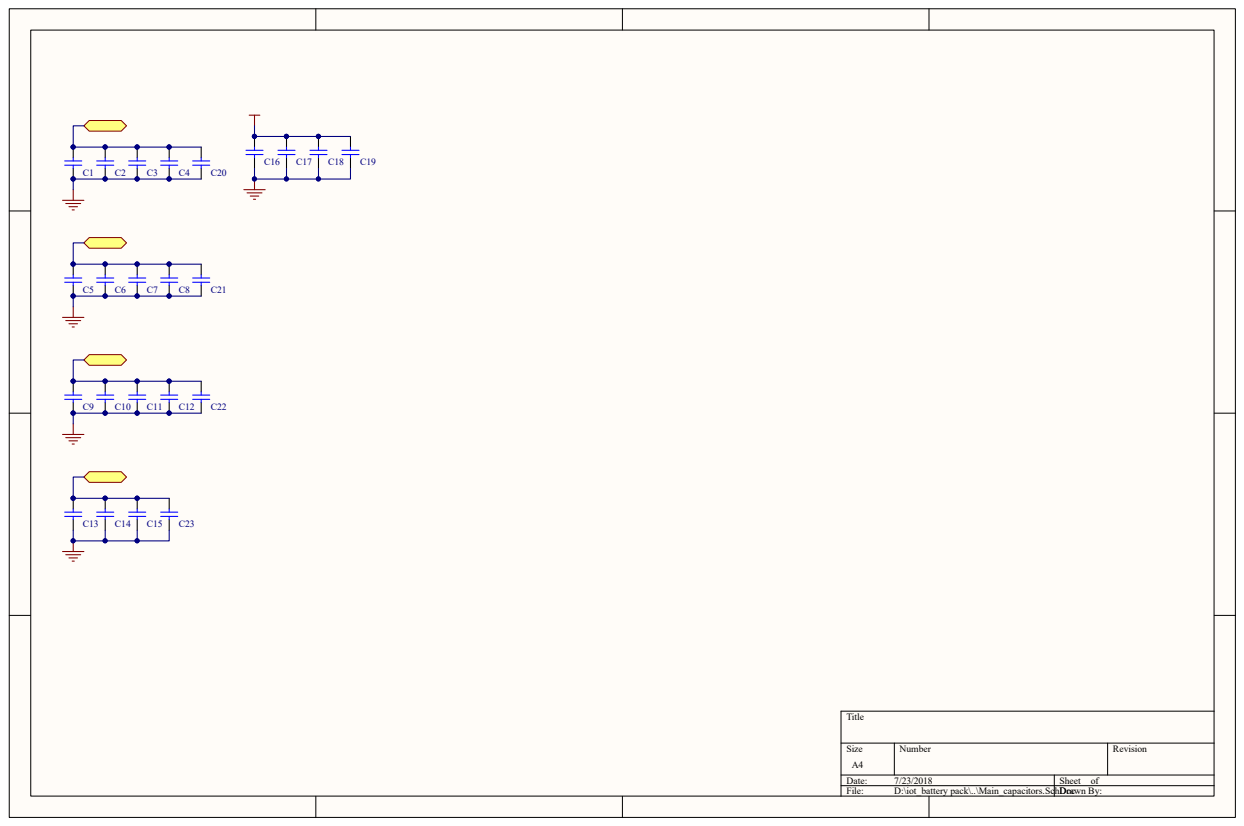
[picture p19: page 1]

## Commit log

2017-05-04 Moved IoT battery pack to a standalone repository
    [IoT-battery-pac-i2c-dump.txt]
2017-05-04 added new version gerber files
2017-05-23 Starting a new branc for modular design
    [IoT-battery-pac-i2c-dump.txt]
2017-05-30 add design files and project structure
    [BOM Purchase Live.xlsx, Battery protector.PcbDoc, Battery protector.SchDoc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]
2017-06-12 Add files via upload
    For PCB file see version _Mainboard 1.1 from now on! V.1.0 was used for prototyping and preliminary testing only. Already set in project file.
    [IRNAS_powerboard.PrjPcb, NodemcuShield_Light_Temp_LCD.PcbDoc, NodemcuShield_Light_Temp_LCD.SchDoc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]
2017-06-12 Add files via upload
    Added pins for external NTC and I2C which go to mainboard.
    [IRNAS_USB_charger.PrjPcb, USB charger.PcbDoc, USB charger.SchDoc]
2017-06-13 Add files via upload
    Changed some EN pins to MCU shield
    [IRNAS_powerboard.PrjPcb, NodemcuShield_Light_Temp_LCD.SchDoc, _Mainboard 1.1.PcbDoc]
2017-06-23 Added power_out_connection_diagram.xml
2017-06-23 Added power_out_connection_diagram.png
2018-07-23 PDF schematics
